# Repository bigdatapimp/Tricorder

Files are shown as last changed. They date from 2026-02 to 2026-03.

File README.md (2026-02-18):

This project is a compact hand held device based on the Arduino Nano 33 BLE sense Rev2 board, inspired by the Tricorder from the Star Trek Franchise
It utilzes a variety of on board sensors as well as GPS to gather a range of data.

There is no license to use this code. I would appriciate a mention if used in your own projects or if you choose to follow the build

By: Tony Dillberg
Feb 2026

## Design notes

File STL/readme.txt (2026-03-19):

These are the 3d Models for all the components used in this project, as well as the STLs for my current design on the case.
I did not create the OLED Models.

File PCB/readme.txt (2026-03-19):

These are the current GERBER files for the PCB design, as well as the current version of the KiCAD files.

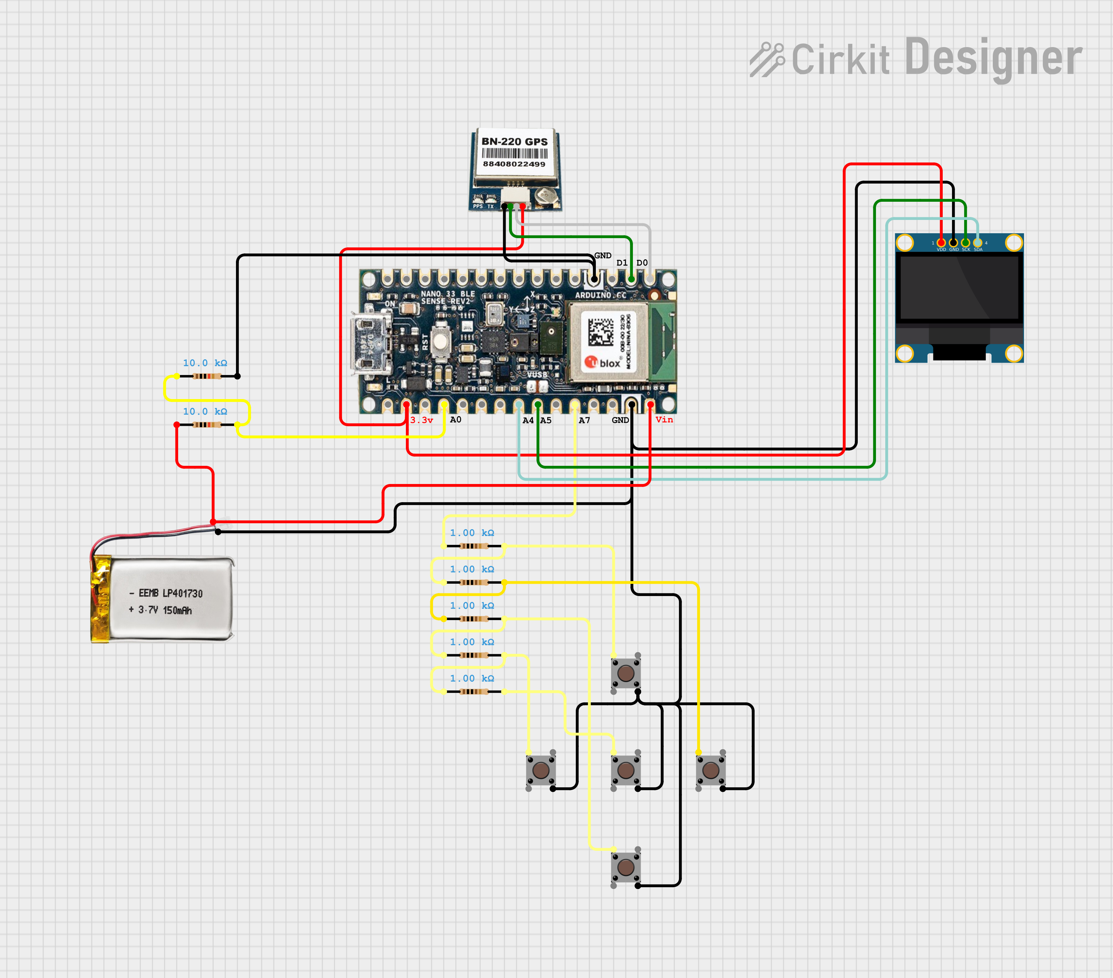
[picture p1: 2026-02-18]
PCB/tricorder_circuit_image.png

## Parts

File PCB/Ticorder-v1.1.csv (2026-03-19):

Reference | Qty | Value | DNP | Exclude from BOM | Exclude from Board | Footprint | Datasheet
A1 | 1 | Arduino_Nano_ESP32 |  |  |  | Module:Arduino_Nano_WithMountingHoles | https://docs.arduino.cc/resources/datasheets/ABX00083-datasheet.pdf
BATT? | 1 | Conn_01x02 |  |  |  | Connector_JST:JST_PH_S2B-PH-K_1x02_P2.00mm_Horizontal | ~
BT1 | 1 | Battery |  |  |  |  | ~
BZ1 | 1 | Buzzer |  |  |  | Buzzer_Beeper:Buzzer_12x9.5RM7.6 | ~
CHG+?,CHG-?,J7,J8 | 4 | Conn_01x01_Pin |  |  |  | Connector_PinHeader_2.54mm:PinHeader_1x01_P2.54mm_Vertical | ~
D1 | 1 | LD271 |  |  |  | LED_THT:LED_D5.0mm_IRGrey | http://www.alliedelec.com/m/d/40788c34903a719969df15f1fbea1056.pdf
DISPLAY1 | 1 | Conn_01x08_Socket |  |  |  | Connector_PinSocket_2.54mm:PinSocket_1x08_P2.54mm_Vertical | ~
DISPLAY2 | 1 | Conn_01x04_Socket |  |  |  | Connector_PinSocket_2.54mm:PinSocket_1x04_P2.54mm_Vertical | ~
INPUTS? | 1 | Conn_01x06_Pin |  |  |  | Connector_PinHeader_2.54mm:PinHeader_1x06_P2.54mm_Horizontal | ~
R1,R2 | 2 | 10K |  |  |  | Resistor_THT:R_Axial_DIN0207_L6.3mm_D2.5mm_P7.62mm_Horizontal | ~
R3 | 1 | 220 |  |  |  | Resistor_THT:R_Axial_DIN0207_L6.3mm_D2.5mm_P7.62mm_Horizontal | ~
SW1 | 1 | SW_SPDT |  |  |  | Button_Switch_THT:SW_Slide_SPDT_Straight_CK_OS102011MS2Q | ~
U1 | 1 | VS1838B |  |  |  | OptoDevice:Vishay_MOLD-3Pin | http://www.vishay.com/docs/82460/tsop45.pdf

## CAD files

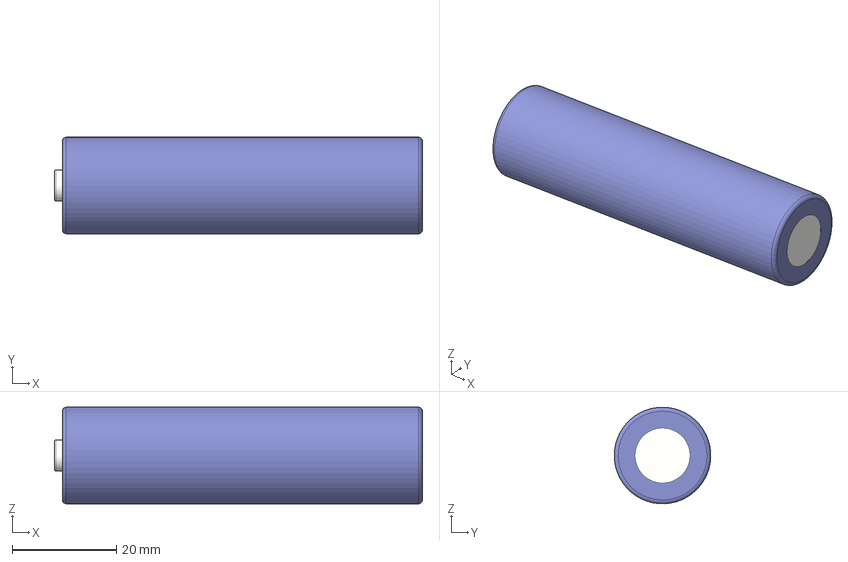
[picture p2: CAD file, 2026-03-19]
STL/Battery - 18650.step
70.5 x 18.5 x 18.5 mm

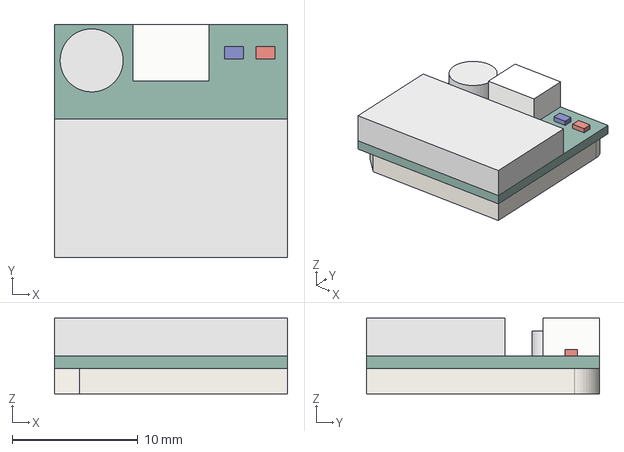
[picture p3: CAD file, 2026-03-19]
STL/GPS.step
18.5 x 18.5 x 6.00 mm

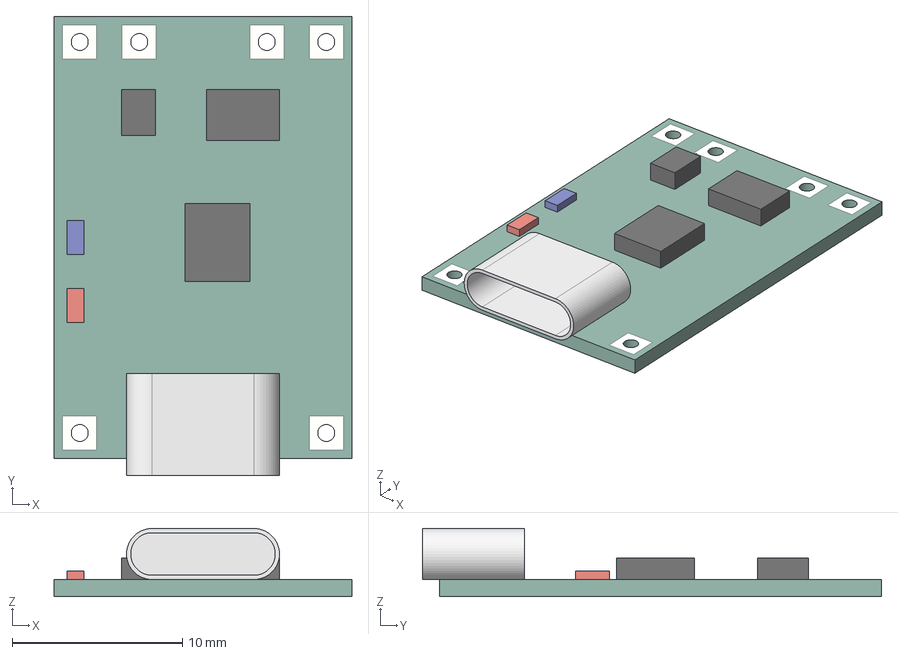
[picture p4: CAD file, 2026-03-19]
STL/TP4056.step
17.5 x 27.0 x 4.00 mm

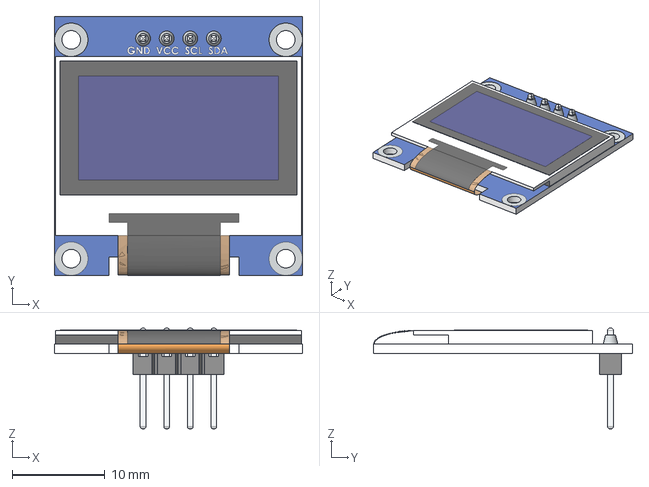
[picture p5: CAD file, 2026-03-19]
STL/OLED-128x64-0.96.step
26.7 x 27.9 x 10.8 mm

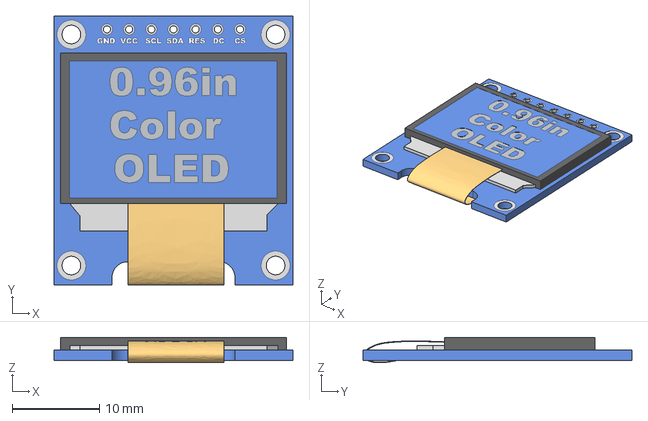
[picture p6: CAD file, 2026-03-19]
STL/0.96in Color OLED.stp
27.4 x 30.8 x 2.92 mm

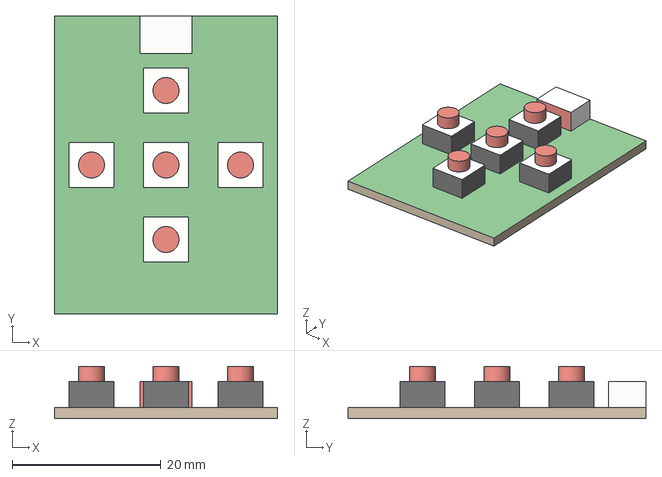
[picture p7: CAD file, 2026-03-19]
STL/Button Board.step
30.0 x 40.0 x 7.00 mm

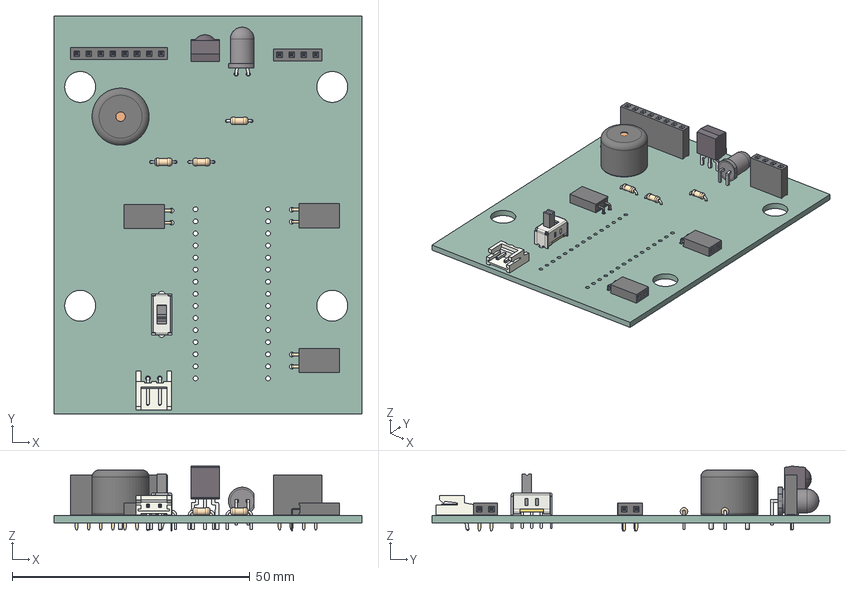
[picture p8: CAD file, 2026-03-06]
STL/Tricorder-v1.0.step
64.8 x 83.7 x 13.6 mm
PinSocket_1x02_P2.54mm_Horizontal x 3
Vishay_MOLD-3Pin
LED_D5.0mm_Horizontal_O1.27mm_Z3.0mm_IRGrey
SW_Slide_SPDT_Straight_CK_OS102011MS2Q
PinSocket_1x08_P2.54mm_Vertical
JST_EH_S2B-EH_1x02_P2.50mm_Horizontal
R_Axial_DIN0204_L3.6mm_D1.6mm_P5.08mm_Horizontal x 3
Buzzer_12x9.5RM7.6
PinSocket_1x04_P2.54mm_Vertical
Tricorder_PCB

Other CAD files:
STL/Ticorder-v1.1.step

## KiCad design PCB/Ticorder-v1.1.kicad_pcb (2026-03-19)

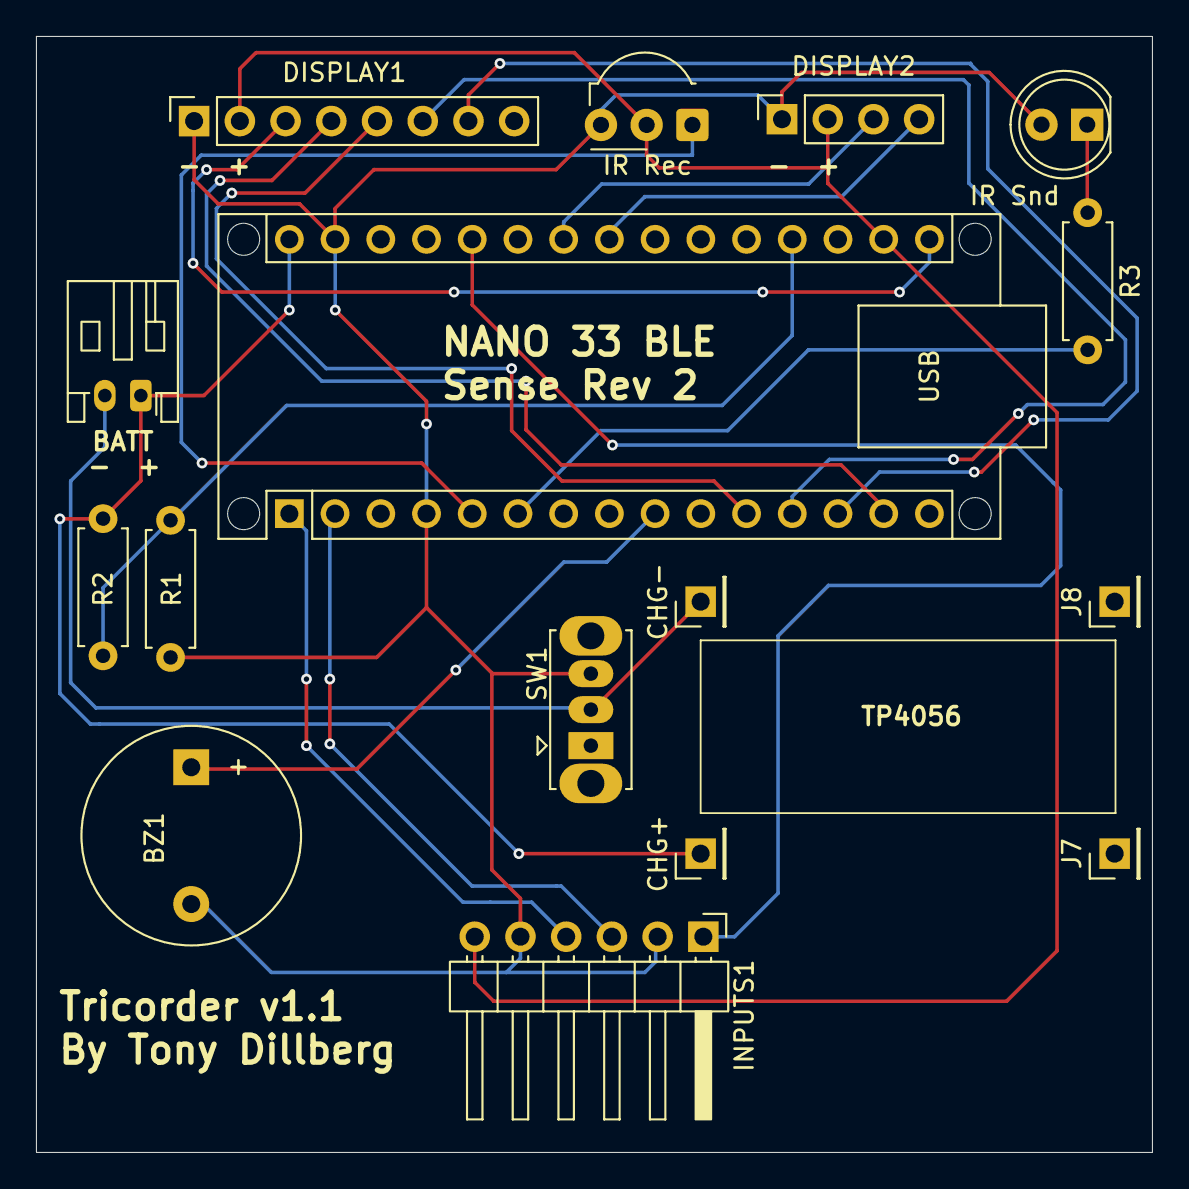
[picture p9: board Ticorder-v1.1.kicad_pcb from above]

Board: 2 copper layers, 62.0 x 62.0 mm, 16 parts (0 on the bottom side), 19 nets.

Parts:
A1: Arduino_Nano_ESP32; Arduino_Nano_WithMountingHoles
BATT: Conn_01x02; JST_PH_S2B-PH-K_1x02_P2.00mm_Horizontal
BZ1: Buzzer; Buzzer_12x9.5RM7.6
CHG+: Conn_01x01_Pin; PinHeader_1x01_P2.54mm_Vertical
CHG-: Conn_01x01_Pin; PinHeader_1x01_P2.54mm_Vertical
DISPLAY1: Conn_01x08_Socket; PinSocket_1x08_P2.54mm_Vertical
DISPLAY2: Conn_01x04_Socket; PinSocket_1x04_P2.54mm_Vertical
INPUTS1: Conn_01x06_Pin; PinHeader_1x06_P2.54mm_Horizontal
IR Rec: VS1838B; Vishay_MOLD-3Pin
IR Snd: LD271; LED_D5.0mm_IRGrey
J7, J8: Conn_01x01_Pin; PinHeader_1x01_P2.54mm_Vertical
R1, R2: 10K; R_Axial_DIN0207_L6.3mm_D2.5mm_P7.62mm_Horizontal
R3: 220; R_Axial_DIN0207_L6.3mm_D2.5mm_P7.62mm_Horizontal
SW1: SW_SPDT; SW_Slide_SPDT_Straight_CK_OS102011MS2Q

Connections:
unnamed: A1.17 (3V3), DISPLAY1.2, DISPLAY2.2, INPUTS1.6, IR Rec.2 (Vs)
unnamed: A1.19 (A0), R1.2, R2.2
unnamed: A1.26 (A7), INPUTS1.1
unnamed: A1.2 (D0/RX), INPUTS1.3
unnamed: A1.1 (D1/TX), INPUTS1.4
unnamed: A1.5 (D2), IR Rec.1 (OUT)
unnamed: A1.6 (D3), R3.2
unnamed: A1.9 (D6), BZ1.1 (+)
unnamed: A1.11 (D8), DISPLAY1.5
unnamed: A1.12 (D9), DISPLAY1.6
unnamed: A1.13 (D10/CS), DISPLAY1.7
unnamed: A1.14 (D11/COPI), DISPLAY1.4
unnamed: A1.16 (D13/SCK), DISPLAY1.3
unnamed: A1.24 (SCL/A5), DISPLAY2.3
unnamed: A1.23 (SDA/A4), DISPLAY2.4
unnamed: A1.30 (VIN), BATT.1, CHG+.1, R1.1
unnamed: BATT.2, CHG-.1, SW1.2 (B)
unnamed: A1.4 (GND), A1.29 (GND), BZ1.2 (-), DISPLAY1.1, DISPLAY2.1, INPUTS1.2, INPUTS1.5, IR Rec.3 (GND), IR Snd.2 (A), R2.1, SW1.3 (C)
unnamed: IR Snd.1 (K), R3.1

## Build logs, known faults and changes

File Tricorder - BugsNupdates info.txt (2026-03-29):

Current Version:  v0.43.32
Known Issues:
Compass laggy / hdg buggy
Menu Lag

General UI/display layout corrections

Upcoming Additions:

LED functions
Shot Timer
Audio Spectrum
Seismometer
BT upload to Phone

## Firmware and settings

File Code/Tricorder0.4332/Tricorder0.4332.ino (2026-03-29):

/*
// -- Tricorder v0.43.32 - By Tony Dillberg
// -- This code is written for the Arduino Nano 33 BLE sense Rev 2
// -- This is for a compact, portable device that utilizes a variety of sensors for basic measurements and readings of various
// -- environmental elements as well as location and direction. It is loosely based on the Tricorder concept from the Star Trek 
// -- franchise.
// --
// -- Split Functions into individual files
// -- Other Minor Code Clean up
// -- 
// -- 
// -- 
*/
#include <Arduino_HS300x.h>
#include <Arduino_LPS22HB.h>
#include <Arduino_BMI270_BMM150.h>
#include <PDM.h>
#include <Adafruit_SSD1306.h>
#include <Adafruit_SSD1331.h>
#include <Adafruit_GFX.h>
#include <TinyGPSPlus.h>
#include <SPI.h>
#define IR_SEND_PIN 3
#define IR_USE_SAMD_TIMER
#include <IRremote.h>
#include "PinDefinitionsAndMore.h" // Set IR_SEND_PIN for different CPU's
#include <TimeLib.h>
#include <Timezone.h>

// --- OLED settings - Screen 1---
#define SCREEN_WIDTH 128
#define SCREEN_HEIGHT 64
#define OLED_RESET -1
Adafruit_SSD1306 display(SCREEN_WIDTH, SCREEN_HEIGHT, &Wire, OLED_RESET);

// --- TFT settings - Screen 2---
#define CS_PIN   10
#define DC_PIN   9
#define RST_PIN  8
// RGB565 Color definitions
#define BLACK    0x0000
#define WHITE    0xFFFF
#define RED      0xF800
#define PINK     0xe8b8
#define PURPLE   0x8010
#define GREEN    0x07E0
#define GREEN2   0x1b62
#define BLUE     0x001F
#define BLUE2    0x6433
#define CYAN     0x07FF
#define MAGENTA  0xF81F
#define YELLOW   0xFFE0
#define GOLD     0xd5c6
#define ORANGE   0xFC00

// Initialize display (96x64 res default for SSD1331)
Adafruit_SSD1331 tft = Adafruit_SSD1331(CS_PIN, DC_PIN, RST_PIN);

// --- Button settings (analog ranges on A7) ---
#define BUTTON_E_MIN 750
#define BUTTON_E_MAX 825
#define BUTTON_UP_MIN 500
#define BUTTON_UP_MAX 570
#define BUTTON_RT_MIN 295
#define BUTTON_RT_MAX 375
#define BUTTON_DN_MIN 0
#define BUTTON_DN_MAX 45
#define BUTTON_LT_MIN 640
#define BUTTON_LT_MAX 725

// --- Button press types ---
#define SHORT_PRESS 1
#define LONG_PRESS 2
#define NO_PRESS 0

#define LONG_PRESS_DURATION 1000 // --- Long press duration (ms) ---
#define DEBOUNCE_DURATION 25 // --- Debounce duration (ms) --- 50 default

// --- Beeper settings ---
#define BEEPER_PIN 6

// --- Enhanced State enum for new menu structure ---
enum State {
  MAIN_MENU,
  GEO_MENU,
  MET_MENU,
  BIO_MENU,
  SYS_MENU,
  UTIL_MENU,
  METALDETECTOR,
  EMFMETER,
  NAVIGATION,
  ATMOSPHERIC,
  DBMETER,
  IRRECEIVER,
  IRSEND,
  BATTERY
};

// --- Menu options ---
const char* mainMenuOptions[5] = {"GEO", "MET", "BIO", "SYS", "UTIL"};
const char* geoMenuOptions[3] = {"MDet", "EMF", "Nav"};
const char* metMenuOptions[2] = {"Atmo", "dB"};
const char* utilMenuOptions[2] = {"IR TX", "IR RX"};
const char* sysMenuOptions[1] = {"Batt"};

int mainMenuCursor = 0;  // 0-4 for main menu
int subMenuCursor = 0;   // For submenu cursors

// --- Global state ---
State currentState = MAIN_MENU;

// --- Button handling variables ---
int lastButton = 0;
unsigned long buttonPressTime = 0;
bool buttonPressed = false;
int stableButton = 0;
unsigned long stableStart = 0;

// --- Navigation specific ---
#define COMPASS_RADIUS 14
#define CENTER_X 68
#define CENTER_Y 25
#define NEEDLE_LENGTH 9
#define DECLINATION 3.44 // board alignment +/- magnetic Declination
bool useMPH = true;   // Default to MPH, toggle with UP
bool useFeet = true;  // Default to Feet, toggle with DOWN
bool useDMS = true; // true = Degrees Minutes Seconds, false = Decimal Degrees
// --- Global variables for sensor fusion ---
float fusedHeading = 0.0;
unsigned long lastFusionTime = 0;
bool isLevel = false;
// --- GPS specific ---
TinyGPSPlus gps;
// US Central Time zone definition
TimeChangeRule usCDT = {"CDT", Second, Sun, Mar, 2, -300};
TimeChangeRule usCST = {"CST", First, Sun, Nov, 2, -360};
Timezone US_Central(usCDT, usCST);

// --- dB Meter specific ---
short sampleBuffer[256];
volatile int samplesRead;
#define REFERENCE_RMS 0.0001
float max_dB = 0.0;

// --- Metal Detector specific ---
#define CALIBRATION_SAMPLES 100
#define DETECTION_THRESHOLD 20.0
float baselineMagnitude = 0.0;

// --- EMF Meter specific ---
#define MAX_EMF 200.0

// --- Atmospheric specific ---
unsigned long lastAtmosphericUpdate = 0;
bool useCelsius = false;  // false = Fahrenheit, true = Celsius
bool useKPa = false;      // false = inHg, true = kPa

// --- irReceiver specific ---
const int IR_RECV_PIN = 2;
bool irDataReceived = false; // Flag to track if data has been received
uint32_t storedIrData = 0;
uint8_t storedIrAddr = 0;
uint8_t storedIrCmd = 0;

// --- irSend specific ---
int irSendCursor = 0;

// --- Battery specific ---
// VIn is read via analog pin A0. Voltage Divider is using two 10kOhm resistors, thus ratio of 2.0
#define VOLTAGE_PIN A0
#define VOLTAGE_DIVIDER_RATIO 2.0  
#define BATTERY_MIN_V 3.35
#define BATTERY_MAX_V 4.25
unsigned long lastBatteryUpdate = 0;

// ---------- Setup Function ----------
void setup() {
  Serial.begin(9600);
  pinMode(A7, INPUT_PULLUP); // input pin for buttons
  pinMode(IR_RECV_PIN, INPUT); // input pin for IR Receiver
  IrSender.begin(IR_SEND_PIN); // output pin for IR Send

  // Initialize OLED - Screen 1
  if (!display.begin(SSD1306_SWITCHCAPVCC, 0x3C)) {
    Serial.println(F("SSD1306 allocation failed"));
    while (true);
  }
  display.clearDisplay();
  display.setTextSize(1);
  display.setTextColor(SSD1306_WHITE);

  // Initialize OLED - Screen 2 (SSD1331)
  tft.begin(8000000);
  tft.setRotation(0);

  // ------- Initialize sensors used across functions ---- 
  if (!HS300x.begin()) {
    Serial.println("Failed to initialize HS300x sensor!");
  }
  if (!BARO.begin()) {
    Serial.println("Failed to initialize LPS22HB sensor!");
  }
  if (!IMU.begin()) {
    Serial.println("Failed to initialize IMU!");
  }

  // --- Initialize PDM for dB Meter ---
  PDM.onReceive(onPDMdata);
  PDM.setGain(70);
  if (!PDM.begin(1, 16000)) {
    Serial.println("Failed to start PDM!");
  }

  // --- Initialize Serial1 for GPS ---
  Serial1.begin(9600);

  // --- Splash Screen - Screen 2---
  tft.fillScreen(BLACK);
  tft.setCursor(0, 8);
  tft.setTextColor(MAGENTA);
  tft.println("________________");
  tft.setTextColor(YELLOW);
  tft.setCursor(0, 16);
  tft.println("Tricorder v0.43");
  tft.setTextColor(BLUE);
  tft.setCursor(0, 30);
  tft.println("By Tony Dillberg");
  tft.setTextColor(PURPLE);
  tft.setCursor(0, 33);
  tft.println("________________");

  // --- Splash Screen - Screen 1---
  display.setCursor(0, 8);
  display.println(" ___________________");
  display.setCursor(30, 16);
  display.println("POWERING ON");
  display.setCursor(40, 30);
  display.println("Stand By");
  display.setCursor(0, 33);
  display.println(" ___________________");
  display.display();
  delay(3500);

  // clear Screen 2
  tft.fillScreen(BLACK);

  // --- Initialize Beeper ---
  pinMode(BEEPER_PIN, OUTPUT);
  playStartupTone();

  // --- Calibrate Metal Detector baseline ---
  calibrateMetalDetector();

  Serial.println("All initialized.");
  Serial.println("Tricorder - v0.4");
  Serial.println("By Tony Dillberg");
}

// ---------- Main Loop ----------
void loop() {
  while (Serial1.available()) {
    gps.encode(Serial1.read());
  }

  int button = getPressedButton(analogRead(A7));
  int pressType = handleButtonPress(button);

  switch (currentState) {
    case MAIN_MENU:
      handleMainMenu(pressType);
      break;
    case GEO_MENU:
      handleGeoMenu(pressType);
      break;
    case MET_MENU:
      handleMetMenu(pressType);
      break;
    case BIO_MENU:
      handleBioMenu(pressType);
      break;
    case SYS_MENU:
      handleSysMenu(pressType);
      break;
    case UTIL_MENU:
      handleUtilMenu(pressType);
      break;
    case METALDETECTOR:
      //tft.fillScreen(BLACK);
      MetalDetector(pressType);
      break;
    case EMFMETER:
      //tft.fillScreen(BLACK);
      EMFMeter(pressType);
      break;
    case NAVIGATION:
      //tft.fillScreen(BLACK);
      Navigation(pressType);
      break;
    case ATMOSPHERIC:
      //tft.fillScreen(BLACK);
      Atmospheric(pressType);
      break;
    case DBMETER:
      //tft.fillScreen(BLACK);
      DBMeter(pressType);
      break;
    case IRRECEIVER:
      //tft.fillScreen(BLACK);
      irReceiver(pressType);
      break;  
    case IRSEND:
      //tft.fillScreen(BLACK);
      IrSend(pressType);
      break;
    case BATTERY:
      //tft.fillScreen(BLACK);
      Battery(pressType);
      break;
  }
  
}

// ---- Main Menu ----
void handleMainMenu(int pressType) {
  display.clearDisplay();
  display.setCursor(20, 9);
  display.setTextSize(1);
  display.println(F("MAIN MENU"));
  
  // Display 5 main menu options
  for (int i = 0; i < 5; i++) {
    int y = 25 + (i * 8);
    display.setCursor(20, y);
    if (i == mainMenuCursor) {
      display.print("> ");
    } else {
      display.print("  ");
    }
    display.println(mainMenuOptions[i]);
  }
  displayGPSClock();
  display.display();
  
  if (pressType == SHORT_PRESS) {
    if (lastButton == 2) { // Up
      mainMenuCursor = (mainMenuCursor - 1 + 5) % 5;
    } else if (lastButton == 4) { // Down
      mainMenuCursor = (mainMenuCursor + 1) % 5;
    } else if (lastButton == 1) { // Enter
      switch (mainMenuCursor) {
        case 0: currentState = GEO_MENU; break;
        case 1: currentState = MET_MENU; break;
        case 2: currentState = BIO_MENU; break;
        case 3: currentState = SYS_MENU; break;
        case 4: currentState = UTIL_MENU; break;
      }
    }
  }
}

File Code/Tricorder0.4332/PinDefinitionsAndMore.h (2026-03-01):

#line 1 "C:\\Users\\Tony\\AppData\\Local\\Temp\\.arduinoIDE-unsaved2026128-6636-1tuij0a.t5me\\TinySender\\PinDefinitionsAndMore.h"
/*
 *  PinDefinitionsAndMore.h
 *
 *  Contains pin definitions for IRremote examples for various platforms
 *  as well as definitions for feedback LED and tone() and includes
 *
 *  Copyright (C) 2021-2023  Armin Joachimsmeyer
 *  armin.joachimsmeyer@gmail.com
 *
 *  This file is part of IRremote https://github.com/Arduino-IRremote/Arduino-IRremote.
 *
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
 */

/*
 * Pin mapping table for different platforms
 *
 * Platform     IR input    IR output   Tone      Core/Pin schema
 * --------------------------------------------------------------
 * DEFAULT/AVR  2           3           4         Arduino
 * ATtinyX5     0|PB0       4|PB4       3|PB3     ATTinyCore
 * ATtiny167    3|PA3       2|PA2       7|PA7     ATTinyCore
 * ATtiny167    9|PA3       8|PA2       5|PA7     Digispark original core
 * ATtiny84      |PB2        |PA4        |PA3     ATTinyCore
 * ATtiny88     3|PD3       4|PD4       9|PB1     ATTinyCore
 * ATtiny3216  14|PA1      15|PA2      16|PA3     MegaTinyCore
 * ATtiny1604   2           3|PA5       %
 * ATtiny816   14|PA1      16|PA3       1|PA5     MegaTinyCore
 * ATtiny1614   8|PA1      10|PA3       1|PA5     MegaTinyCore
 * MKR*         1           3           4
 * SAMD         2           3           4
 * ESP8266      14|D5       12|D6       %
 * ESP32        15          4          27
 * ESP32-C3     2           3           4
 * BluePill     PA6         PA7       PA3
 * APOLLO3      11          12          5
 * RP2040       3|GPIO15    4|GPIO16    5|GPIO17
 */
//#define _IR_MEASURE_TIMING // For debugging purposes.

#if defined(__AVR__)
#if (defined(__AVR_ATtiny25__) || defined(__AVR_ATtiny45__) || defined(__AVR_ATtiny85__)) && defined(PIN_PB0) // Digispark board. For use with ATTinyCore.
#include "ATtinySerialOut.hpp" // TX is at pin 2 - Available as Arduino library "ATtinySerialOut". Saves 700 bytes program memory and 70 bytes RAM for ATtinyCore.
#define IR_RECEIVE_PIN  PIN_PB0
#define IR_SEND_PIN     PIN_PB4 // Pin 2 is serial output with ATtinySerialOut. Pin 1 is internal LED and Pin3 is USB+ with pullup on Digispark board.
#define TONE_PIN        PIN_PB3
#define _IR_TIMING_TEST_PIN PIN_PB3

#  elif defined(__AVR_ATtiny87__) || defined(__AVR_ATtiny167__) // Digispark pro board
#include "ATtinySerialOut.hpp" // Available as Arduino library "ATtinySerialOut"
// For ATtiny167 Pins PB6 and PA3 are usable as interrupt source.
#    if defined(ARDUINO_AVR_DIGISPARKPRO)
// For use with Digispark original core
#define IR_RECEIVE_PIN   9 // PA3 - on Digispark board labeled as pin 9
//#define IR_RECEIVE_PIN  14 // PB6 / INT0 is connected to USB+ on DigisparkPro boards
#define IR_SEND_PIN      8 // PA2 - on Digispark board labeled as pin 8
#define TONE_PIN         5 // PA7 - on Digispark board labeled as pin 5
#define _IR_TIMING_TEST_PIN 10 // PA4
#    elif  !defined(PIN_PA3)
#error ATtiny87 or ATtiny167 is not supported for the selected core. Please extend PinDefinitionsAndMore.h.
#    else
// For use with ATTinyCore
#define IR_RECEIVE_PIN  PIN_PA3 // On Digispark board labeled as pin 9 - INT0 is connected to USB+ on DigisparkPro boards
#define IR_SEND_PIN     PIN_PA2 // On Digispark board labeled as pin 8
#define TONE_PIN        PIN_PA7 // On Digispark board labeled as pin 5
#    endif

#  elif defined(__AVR_ATtiny84__) && defined(PIN_PB2) // For use with ATTinyCore
#include "ATtinySerialOut.hpp" // Available as Arduino library "ATtinySerialOut". Saves 128 bytes program memory.
#define IR_RECEIVE_PIN   PIN_PB2 // INT0
#define IR_SEND_PIN      PIN_PA4
#define TONE_PIN         PIN_PA3
#define _IR_TIMING_TEST_PIN PIN_PA5

#  elif defined(__AVR_ATtiny88__) && defined(PIN_PD3) // MH-ET Tiny88 board. For use with ATTinyCore.
#include "ATtinySerialOut.hpp" // Available as Arduino library "ATtinySerialOut". Saves 128 bytes program memory.
// Pin 6 is TX, pin 7 is RX
#define IR_RECEIVE_PIN   PIN_PD3 // 3 - INT1
#define IR_SEND_PIN      PIN_PD4 // 4
#define TONE_PIN         PIN_PB1 // 9
#define _IR_TIMING_TEST_PIN PIN_PB0 // 8

#  elif (defined(__AVR_ATtiny1616__) || defined(__AVR_ATtiny3216__) || defined(__AVR_ATtiny3217__)) && defined(PIN_PA1) // For use with megaTinyCore
// Tiny Core Dev board
// https://www.tindie.com/products/xkimi/tiny-core-16-dev-board-attiny1616/ - Out of Stock
// https://www.tindie.com/products/xkimi/tiny-core-32-dev-board-attiny3217/ - Out of Stock
#define IR_RECEIVE_PIN   PIN_PA1 // 14 use 18 instead of PIN_PA1 for TinyCore32
#define IR_SEND_PIN      PIN_PA2 // 15, 19 for TinyCore32
#define TONE_PIN         PIN_PA3 // 16, 20 for TinyCore32
#define APPLICATION_PIN  PIN_PC3 // 13, PIN_PA0 is RESET
#undef LED_BUILTIN               // No LED available on the TinyCore 32 board, take the one on the programming board which is connected to the DAC output
#define LED_BUILTIN      PIN_PA6 // use 2 instead of PIN_PA6 for TinyCore32
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

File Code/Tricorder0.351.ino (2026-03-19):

/*
// -- Tricorder v0.35.1 - By Tony Dillberg
// -- This code is written for the Arduino Nano 33 BLE sense Rev 2
// -- This is for a compact, portable device that utilizes a variety of sensors for basic measurements and readings of various
// -- environmental elements as well as location and direction. It is loosely based on the Tricorder concept from the Star Trek 
// -- franchise.
*/

#include <Arduino_HS300x.h>
#include <Arduino_LPS22HB.h>
#include <Arduino_BMI270_BMM150.h>
#include <PDM.h>
#include <Adafruit_SSD1306.h>
#include <Adafruit_GFX.h>
#include <TinyGPSPlus.h>



// --- OLED settings ---
#define SCREEN_WIDTH 128
#define SCREEN_HEIGHT 64
#define OLED_RESET -1
Adafruit_SSD1306 display(SCREEN_WIDTH, SCREEN_HEIGHT, &Wire, OLED_RESET);

// --- Button settings (analog ranges on A7) ---
#define BUTTON_E_MIN 775
#define BUTTON_E_MAX 795
#define BUTTON_UP_MIN 525
#define BUTTON_UP_MAX 545
#define BUTTON_RT_MIN 325
#define BUTTON_RT_MAX 345
#define BUTTON_DN_MIN 0
#define BUTTON_DN_MAX 20
#define BUTTON_LT_MIN 665
#define BUTTON_LT_MAX 695

// --- Button press types ---
#define SHORT_PRESS 1
#define LONG_PRESS 2
#define NO_PRESS 0

// --- Long press duration (ms) ---
#define LONG_PRESS_DURATION 1000

// --- Debounce duration (ms) ---
#define DEBOUNCE_DURATION 50

// --- States ---
enum State {
  MENU,
  ATMOSPHERIC,
  NAVIGATION,
  DBMETER,
  METALDETECTOR,
  EMFMETER,
  BATTERY
};

// --- Menu options ---
const char* menuOptions[6] = {"1.Atmo", "2.Nav", "3.dB", "4.MDet", "5.EMF", "6.Batt"};
int menuCursor = 0; // 0 to 5

// --- Global state ---
State currentState = MENU;

// --- Button handling variables ---
int lastButton = 0;
unsigned long buttonPressTime = 0;
bool buttonPressed = false;
int stableButton = 0;
unsigned long stableStart = 0;

// --- Navigation specific ---
#define COMPASS_RADIUS 10
#define CENTER_X 115
#define CENTER_Y 45
#define NEEDLE_LENGTH 7
#define DECLINATION 90.0

// --- Global variables for sensor fusion ---
float fusedHeading = 0.0;
unsigned long lastFusionTime = 0;

// --- GPS specific ---
TinyGPSPlus gps;


// --- dB Meter specific ---
short sampleBuffer[256];
volatile int samplesRead;
#define REFERENCE_RMS 0.0001
float max_dB = 0.0; // Variable to track peak dB

// --- Metal Detector specific ---
#define CALIBRATION_SAMPLES 100
#define DETECTION_THRESHOLD 20.0
float baselineMagnitude = 0.0;

// --- EMF Meter specific ---
#define MAX_EMF 200.0

// --- Atmospheric update timer ---
unsigned long lastAtmosphericUpdate = 0;

// --- Battery specific ---
// VIn is read via analog pin A0. Voltage Divider is using two 10kOhm resistors, thus ratio of 2.0
#define VOLTAGE_PIN A0
#define VOLTAGE_DIVIDER_RATIO 2.0  
#define BATTERY_MIN_V 3.0
#define BATTERY_MAX_V 4.2
unsigned long lastBatteryUpdate = 0;


// ---------- Setup Funtion ----------
void setup() {
  Serial.begin(9600);
  //while (!Serial);

  pinMode(A7, INPUT_PULLUP);

  // Initialize OLED
  if (!display.begin(SSD1306_SWITCHCAPVCC, 0x3C)) {
    Serial.println(F("SSD1306 allocation failed"));
    while (true);
  }
  display.clearDisplay();
  display.setTextSize(1);
  display.setTextColor(SSD1306_WHITE);

  // ------- Initialize sensors used across functions ---- 
  if (!HS300x.begin()) {
    Serial.println("Failed to initialize HS300x sensor!");
  }
  if (!BARO.begin()) {
    Serial.println("Failed to initialize LPS22HB sensor!");
  }
  if (!IMU.begin()) {
    Serial.println("Failed to initialize IMU!");
  }

  // --- Initialize PDM for dB Meter ---
  PDM.onReceive(onPDMdata);
  PDM.setGain(70);
  if (!PDM.begin(1, 16000)) {
    Serial.println("Failed to start PDM!");
  }

  // --- Initialize Serial1 for GPS ---
  Serial1.begin(9600);


  // --- Splash Screen ---
    display.setCursor(0, 8);
    display.println(" ___________________");
    display.setCursor(0, 16);
    display.println(" Tricorder - v0.35.1");
    display.setCursor(0, 30);
    display.println("  By Tony Dillberg");
    display.setCursor(0, 33);
    display.println(" ___________________");
    display.display();
    delay(3500);

  // --- Calibrate Metal Detector baseline ---
  calibrateMetalDetector();

  Serial.println("All initialized.");
  Serial.println("Tricorder - v0.35.1");
  Serial.println("By Tony Dillberg");
}

// ---------- Main Loop ----------
void loop() {
  int button = getPressedButton(analogRead(A7));
  int pressType = handleButtonPress(button);

  switch (currentState) {
    case MENU:
      handleMenu(pressType);
      break;
    case ATMOSPHERIC:
      runAtmospheric(pressType);
      break;
    case NAVIGATION:
      runNavigation(pressType);
      break;
    case DBMETER:
      runDBMeter(pressType);
      break;
    case METALDETECTOR:
      runMetalDetector(pressType);
      break;
    case EMFMETER:
      runEMFMeter(pressType);
      break;
    case BATTERY:  // Added case for battery
      runBattery(pressType);
      break;
  }
}

void handleMenu(int pressType) {
  // -- Display menu in two columns
  display.clearDisplay();
  display.setCursor(0, 16);
  display.println(F("Select Function"));

  // -- Column 1
  display.setCursor(10, 30);
  display.println(menuOptions[0]);
  display.setCursor(10, 40);
  display.println(menuOptions[1]);
  display.setCursor(10, 50);
  display.println(menuOptions[2]);

  // -- Column 2
  display.setCursor(64, 30);
  display.println(menuOptions[3]);
  display.setCursor(64, 40);
  display.println(menuOptions[4]);
  display.setCursor(64, 50);  
  display.println(menuOptions[5]);

  // Highlight cursor
  int col = menuCursor / 3; // 0 or 1
  int row = menuCursor % 3; // 0,1,2
  int x = col * 54 + 10; // Start at 10 or 64
  int y = 30 + row * 10; // 30, 45, 60
  display.setCursor(x - 10, y);
  display.print(">");

  display.display();

  // --- Handle presses ---
  if (pressType == SHORT_PRESS) {
    if (lastButton == 2) { // Up
      menuCursor = (menuCursor - 1 + 6) % 6;
    } else if (lastButton == 4) { // Down
      menuCursor = (menuCursor + 1) % 6;
    } else if (lastButton == 5) { // Left
      if (menuCursor >= 3) menuCursor -= 3;
    } else if (lastButton == 3) { // Right
      if (menuCursor < 3) menuCursor += 3;
    } else if (lastButton == 1) { // Enter
      currentState = (State)(menuCursor + 1); // MENU=0, so +1
    }
  }
}
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

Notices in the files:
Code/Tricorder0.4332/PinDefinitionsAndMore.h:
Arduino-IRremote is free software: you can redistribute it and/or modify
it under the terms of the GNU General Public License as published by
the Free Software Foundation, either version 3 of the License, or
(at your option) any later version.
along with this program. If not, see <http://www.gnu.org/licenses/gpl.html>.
